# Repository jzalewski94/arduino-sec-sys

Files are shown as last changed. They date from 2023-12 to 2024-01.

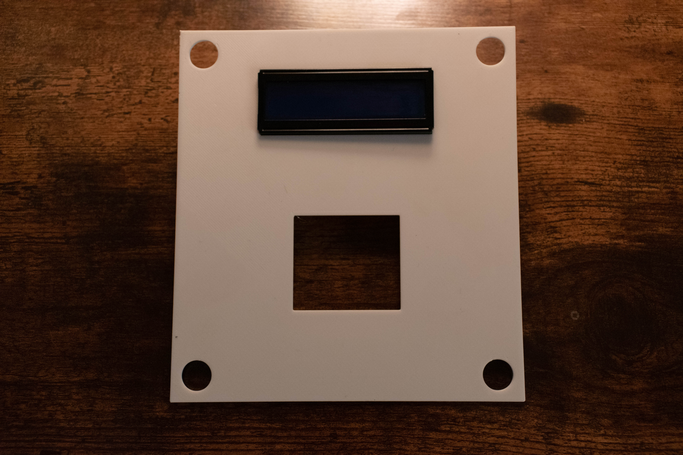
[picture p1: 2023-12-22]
models+3d-files/photos/20231221-DSC_1753.jpg

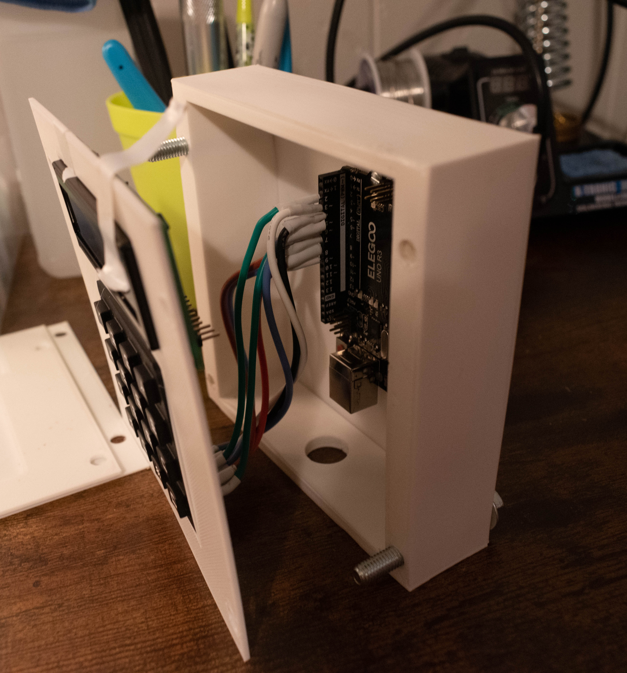
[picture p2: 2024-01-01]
models+3d-files/photos/20240102-DSC_1849.jpg

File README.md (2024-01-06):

Making a security system using an Arduino board. This will be a very basic system but may become more complicated in the future. I'm recording my steps here for anyone who wants to follow along to make a system like this. 

It will have horns, a magnetic sensor, and a control panel for the user to arm/disarm and set a password for the system. I plan on adding battery backup in the future to help protect against damage or power failure. I will also list the items used here and my electrical diagrams and schematics, along with any models and 3d print files I may generate or create. This will be modeled by myself to the best of my abilities. 

Items Used:

(2) 12V, 15W Horns (Bought)

(1) Magnetic Door Sensor (Bought)

(1) 3D Printed Control Box (Printed)

Amazon Link: https://www.amazon.com/hz/wishlist/ls/1QPFONZCPDYVN?ref_=wl_share

Mockup Update 1/6/2024:

The latest model files and mock-up files are the finalized mock-up models. I will now work on an Alpha design that will look more visually pleasing while remaining durable. 
The code for the controller is still being developed and worked on as well.

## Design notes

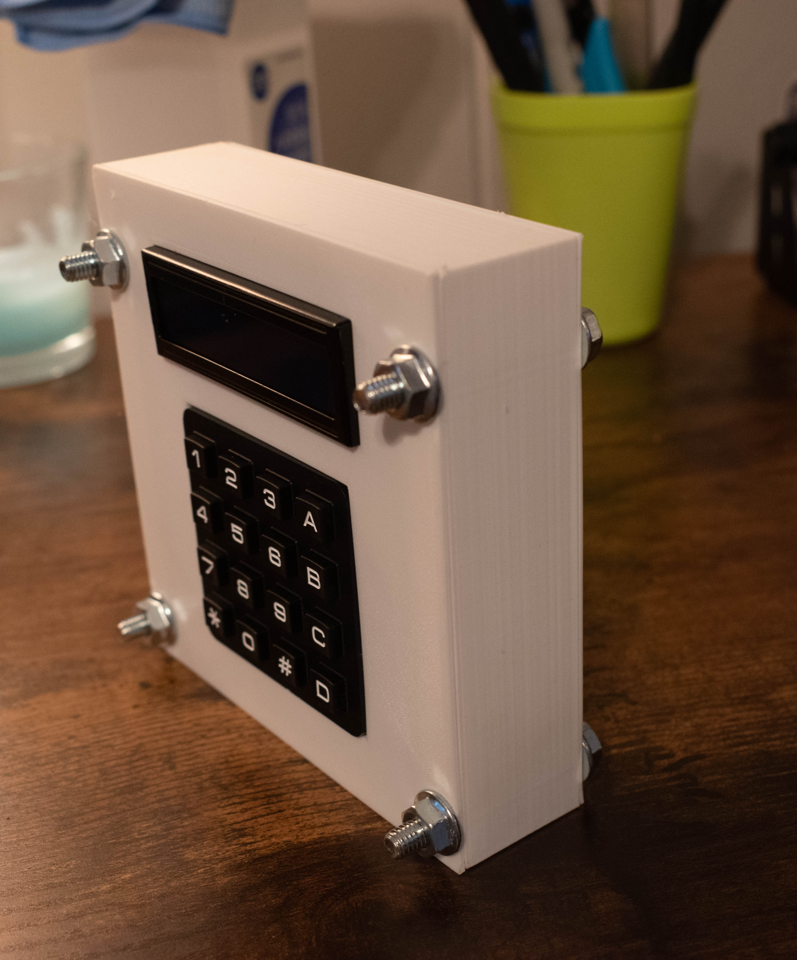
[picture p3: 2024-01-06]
models+3d-files/photos/20240107-DSC_1851.jpg

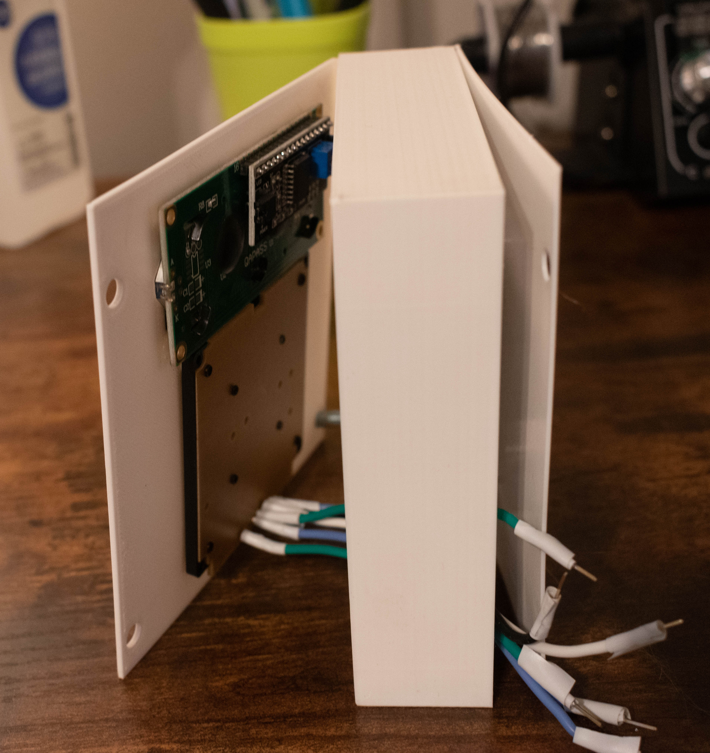
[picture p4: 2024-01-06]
models+3d-files/photos/20240107-DSC_1853.jpg

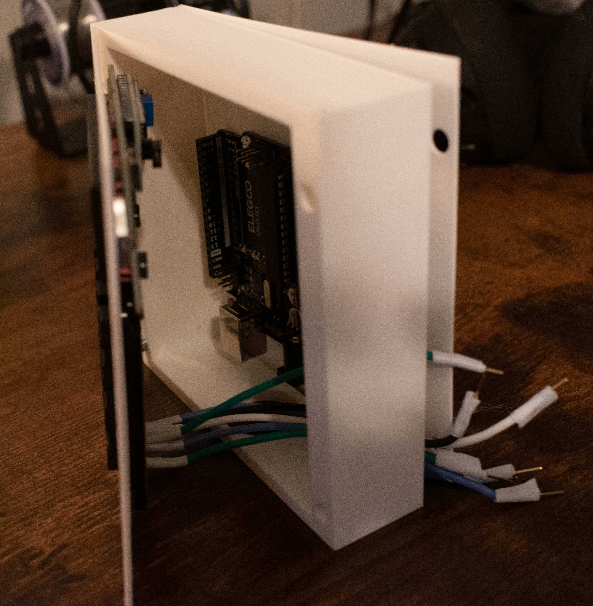
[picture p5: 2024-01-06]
models+3d-files/photos/20240107-DSC_1852.jpg

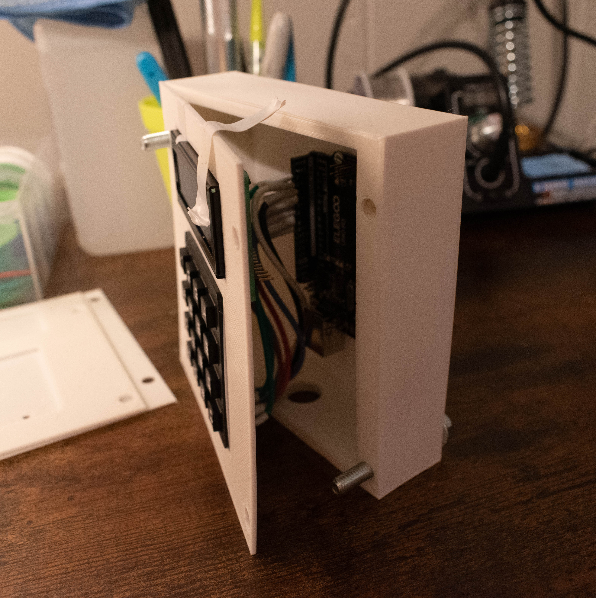
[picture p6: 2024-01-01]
models+3d-files/photos/20240102-DSC_1848.jpg

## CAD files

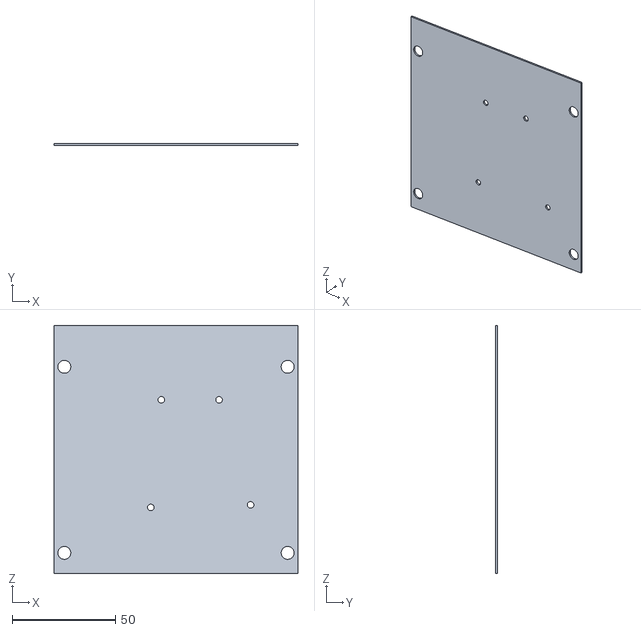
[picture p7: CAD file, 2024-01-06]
models+3d-files/back-plate-1.2.stl
118.0 x 1.00 x 120.0

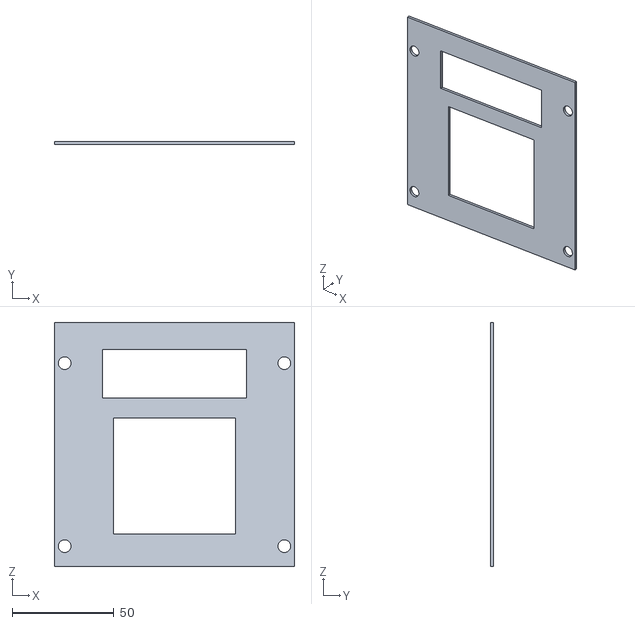
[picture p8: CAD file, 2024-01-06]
models+3d-files/front-plate-2.2.stl
118.0 x 1.50 x 120.0

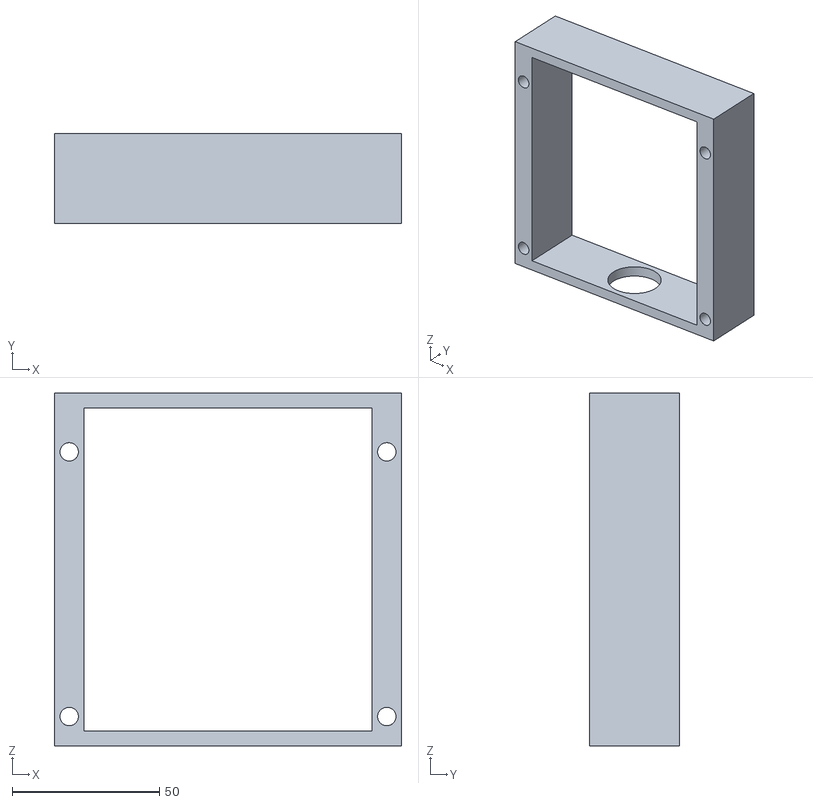
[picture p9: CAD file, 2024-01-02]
models+3d-files/housing-2.1.stl
118.0 x 30.5 x 120.0

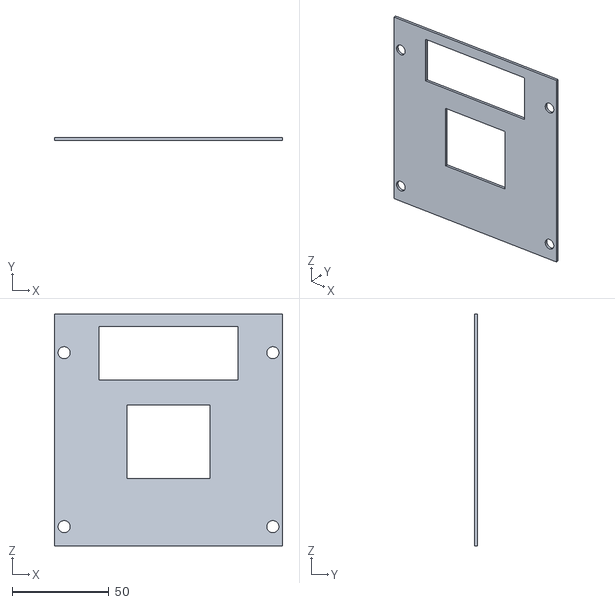
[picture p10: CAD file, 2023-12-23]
models+3d-files/front-plate-1.5.stl
118.0 x 1.50 x 120.0

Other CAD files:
models+3d-files/back-plate-1.1.stl
models+3d-files/front-plate-2.1.stl
models+3d-files/back-plate-1.0.stl
models+3d-files/front-plate-2.0.stl
models+3d-files/housing-2.0.stl
models+3d-files/front-plate-1.4.stl
models+3d-files/control-panel-mockup-1.4.f3d
models+3d-files/control-panel-mockup-2.0.f3d
models+3d-files/control-panel-mockup-2.2.f3d
models+3d-files/control-panel-mockup-2.3.f3d
models+3d-files/control-panel-mockup-2.4.f3d

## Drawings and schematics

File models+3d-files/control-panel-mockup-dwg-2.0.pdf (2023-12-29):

# 56.9 ⁶⁰

# 27.5 ⁷² Ø6.25

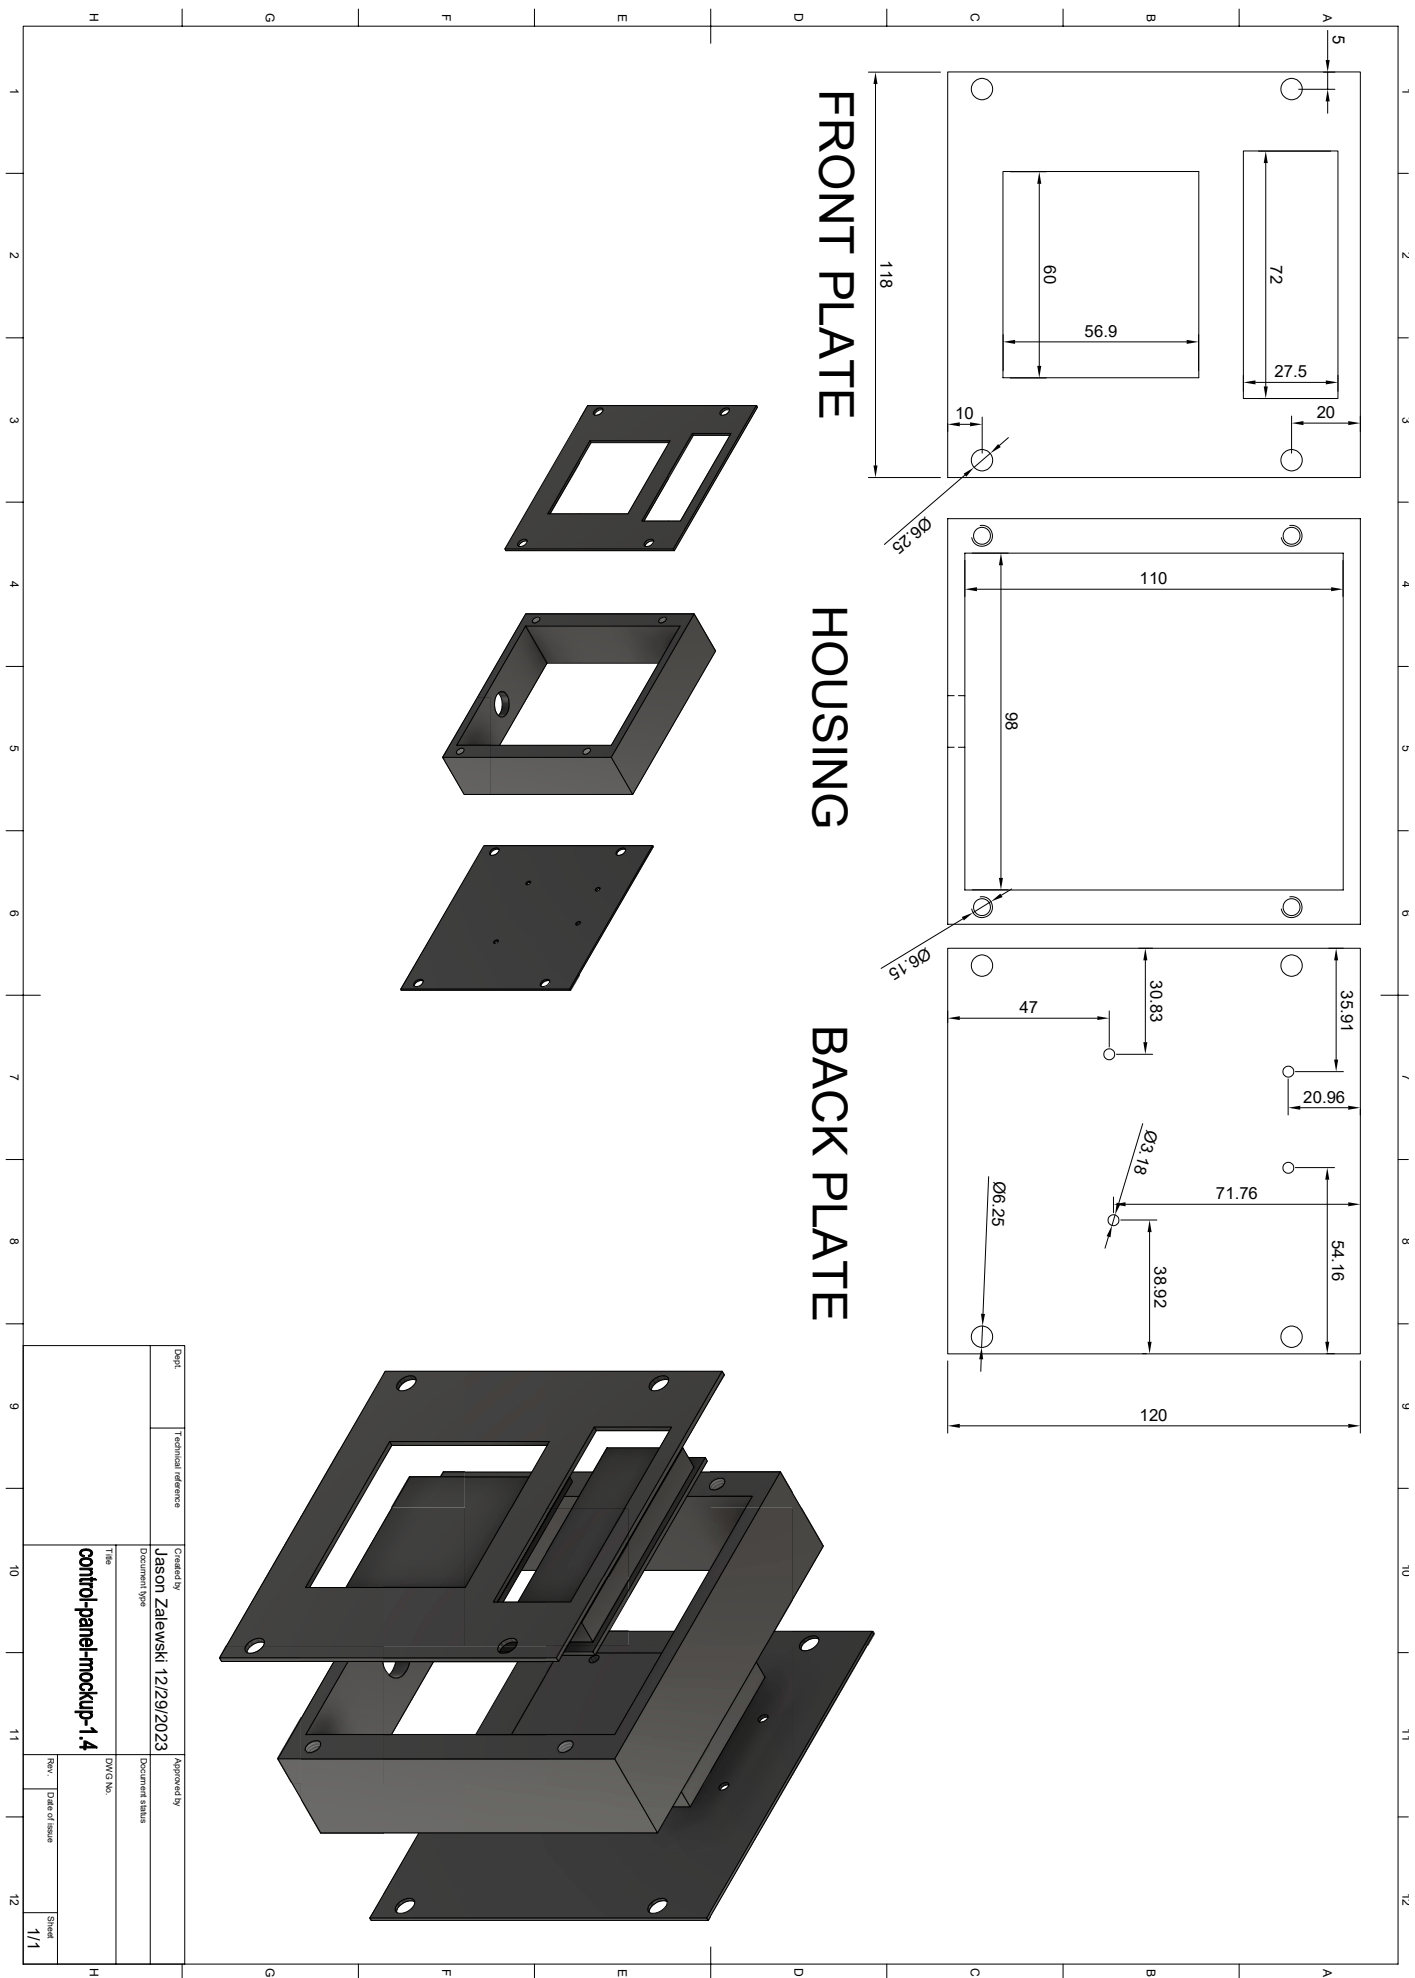
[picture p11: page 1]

2 1 3 4 5 6 7 8 9 10 11 12 2 1 3 4 5 6 7 8 9 10 11 12 HGFEDCBA HGFEDCBA Dept. Technical reference Created by Approved by Title DWG No. Document type Document status Rev. Date of issue Sheet 12/29/2023 1/1 Jason Zalewski 118
10 20 FRONT PLATE HOUSING BACK PLATE

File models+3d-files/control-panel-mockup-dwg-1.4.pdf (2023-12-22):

118 120

72

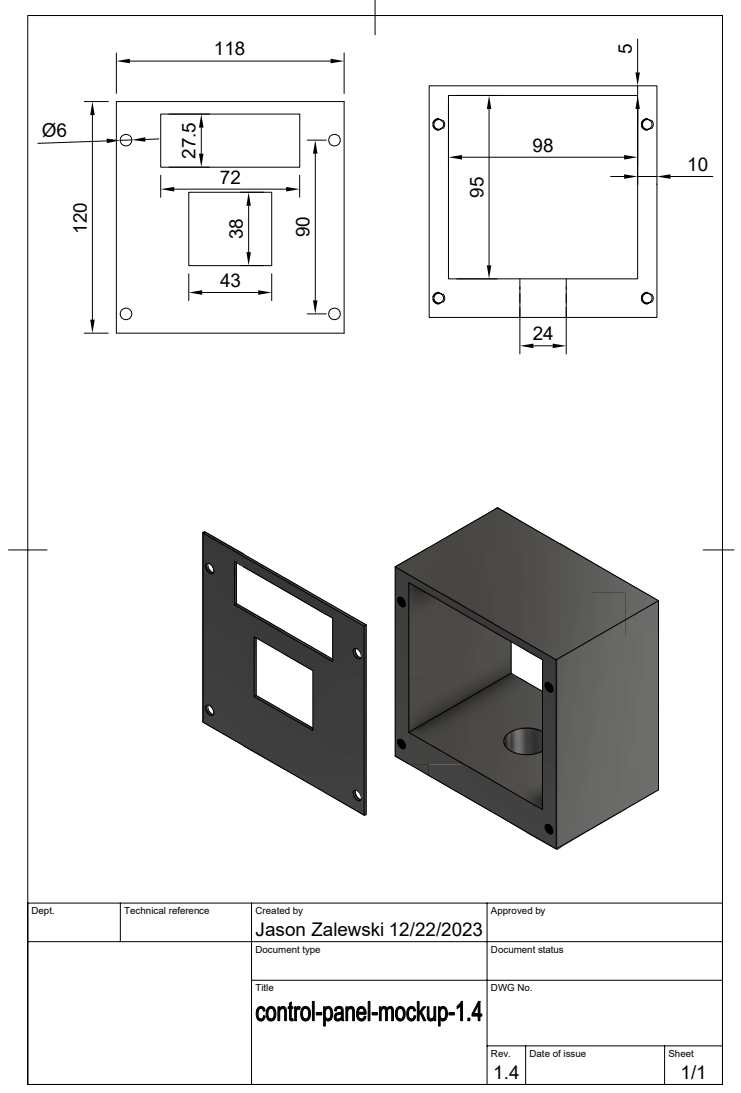
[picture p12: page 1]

Dept. | Technical reference | Created by Jason Zalewski 12/22/2023 | Approved by

Document type | Document status

Title | | | DWG No.

Rev. 1.4 | Date of issue | Sheet 1/1

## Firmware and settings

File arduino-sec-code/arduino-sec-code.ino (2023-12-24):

/*Here I am using the keypad libary to help me easily make a functional keypad.*/
#include <Keypad.h>




/*I have a bunch of consts here, things that aren't changing such as:
 * Armed/Disarmed LED lights on digital pin 10 and 11.
 * Door sensor on digital pin 13.
 * 
 * The row and column numbers because my physical keypad consists of a 4x4 Matrix.
 * 
 * Hard set usrpassword String. I am not currently using this, but will be worked on in the future.
 */
const int armedLED = 10;
const int disarmedLED = 11;
const int doorSensor = 13;
const int rowNum = 4;
const int colNum = 4;
const String usrPassword = "2194";







/*
 * Some booleans here, such as:
 * Is the alarm active/armed?
 * Did the password attempt succeed?
 * Has the alarm been triggered? (This one is being used the most)
 */
bool alarmActive = true;
bool passwordAttemptSucceed = false;

bool alarmTriggered = false;


/*
 * Int to hold the on/off value of my door sensor.
 */
int doorSensorVal = 0;



/*
 * I grabbed this code from the internet, so it was not written by me. 
 * You're making an array called keys that consists of 2 different axis (Row...Col...)
 * This is the physical layout of the keypad.
 */
char keys [rowNum][colNum] = {
  {'1','2','3', 'A'},
  {'4','5','6', 'B'},
  {'7','8','9', 'C'},
  {'*','0','#', 'D'}
};

/*
 * Here we are making variables of the byte type that will let us know where to place our wires into what pins. 
 * My keypad did not come with any documentation so this was trial and error for me.
 */
byte pin_rows[rowNum] = {9, 8, 7, 6}; //connect to the row pinouts of the keypad
byte pin_column[colNum] = {5, 4, 3, 2}; //connect to the column pinouts of the keypad


/*
 * I do not know how this function works, but this is essentially creating our keypad using the data above. 
 */
Keypad keypad = Keypad( makeKeymap(keys), pin_rows, pin_column, rowNum, colNum );

 
 
 /*
  * WIP Function. This and AlarmTriggered are WIP.
  */
 void PasswordAuth(){
    bool passwordCorr = false;
    int keyPresses = 0;
    char usrAttempt[3];

 
 
    while (passwordCorr == false && alarmTriggered == true){
      char keyPressed = keypad.getKey();

      switch(keypad.getState()){        
        case PRESSED:
        if( keyPressed == '2'){
          usrAttempt[0] = keyPressed;
          Serial.println(usrAttempt);
        }else if ( keyPressed == '1'){
          usrAttempt[1] = keyPressed;
          Serial.println(usrAttempt);
        }else if( keyPressed == '9'){
          usrAttempt[2] = keyPressed;
          Serial.println(usrAttempt);
        }else if( keyPressed == '4'){
          usrAttempt[3] = keyPressed;
          Serial.println(usrAttempt);

    }
  }
      if(usrAttempt[0] == '2' && usrAttempt[1] == '1' && usrAttempt[2] == '9' && usrAttempt[3] == '4'){
        
        Serial.println(usrAttempt);
        for(int i = 0; i < 4; i++){
          usrAttempt[i] = 0;
        }
        Serial.println(usrAttempt);
        passwordCorr = true;
         alarmTriggered = false;
        Serial.println(alarmTriggered);
        Serial.println(passwordCorr);
      }
      
}


 return;
}




/*
 * In my setup function, I open the serial monitor so I can use it for debugging.
 * I'm setting my LEDs to be an OUTPUT and the door sensor to be an INPUT.
 */
void setup() {
 Serial.begin(9600);

 pinMode(armedLED, OUTPUT);
 pinMode(disarmedLED, OUTPUT);
 pinMode(doorSensor, INPUT);

}



/*
 * In my loop function, I'm setting the doorSensorVal to read what ever is on digital pin 13(doorSensor).
 * 
 */
void loop() {
  doorSensorVal = digitalRead(doorSensor);
  
  /*
   * This is my first if statement in the program. It's checking to see if the door sensor value has changed.
   * If it switches to an ON state (1), it will set the alarm triggered value to TRUE and call the AlarmTriggered method.
   */
   if(doorSensorVal < 1){
    alarmTriggered = false;
  } else if(doorSensorVal == 1){
    alarmTriggered = true;
    AlarmTriggered();
    
  }



   /*
    * This IF statement is essentially here to control LEDs and give the user feedback. 
    * The first IF statement is checking to see if the alarm is active, not triggered, and the sensors aren't going off.
    * If all of this is met, it will set the armed LED to ON( HIGH) and print an message stating the alarmed is armed.
    *
    *The second IF statement is checking to see if the alarm is not active, has been reset and if the door sensor value isn't
    *being triggered (0). If all of these are met, it will ask if you want to re-arm the alarm. This IF statement should only be
    *called once the AlarmTriggered method has been satisified. 
    */
  if(alarmActive == true && alarmTriggered == false && doorSensorVal < 1){
    digitalWrite(armedLED, HIGH);
    Serial.println("Alarmed Armed.");
  } else if(alarmActive == false && alarmTriggered == false && doorSensorVal < 1){
    Serial.println("Do you wish to re arm the alarm?");
  }


  

}



/*
 * The AlarmTriggered method should only be called if the doorSensorVal goes off (ON, 1). The user will have to make sure
 * the door is securely closed or off the sensor before trying to reset the alarm. 
 */
void AlarmTriggered(){
    
      
      /*
       * When this method is called, it sets the alarm to be inactive. In the future, I will have to make the re-arming function. 
       * 
       * It is also setting the LEDs to their correct setting. (Red = HIGH for alarm on/inactive. Green = LOW)
       * An 'Alarm Triggered!" message also goes off.
       */
      alarmActive = false;
      digitalWrite(armedLED, LOW);
      digitalWrite(disarmedLED, HIGH);
      Serial.println("Alarmed Triggered!");

      
    /*
     * Here is a while loop that continues to run while the alarm variable is true. This is an WIP.
     */
     while(alarmTriggered == true){
        char passwordAttempt[4];
        int keyPressed = 4;
        int i = 0;
        int passwordCountdown = 10;
        Serial.println("Please enter the disarm password.");
        Serial.println("You have 10 seconds to enter the password, followed by #.");
        Serial.println(doorSensorVal);
        PasswordAuth();
       

          }

        }
        




 
  

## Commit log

2023-12-20 Added mock up for my control panel for the security system. This was made in Fusion360.
    Added the 3d file for the cover for my control panel.
    [control-box-frontcover.stl, control-box-mockup.f3d]
2023-12-20 Printed copy 1.0 of the face plate. Thru holes were way too big for the printer to accurately make. Adjusted the overall dimensions of the control panel housing and the front cover.
    Housing L x W: 150mm x 138mm
    Front Panel Cover L x W: 150mm x 138mm
    Front Panel Thru-Holes: 12mm Diameter
    Housing Tapped Holes: 10.27mm Diameter x 40mm Long (M12x1.75 Screw, RH Threads)
    Redid the overall mockup of the Control Planel. Added a mockup Elegoo PCB that will sit inside the panel on the side. Adjust mock up LED and Keypad
    to fit inside the panel and have no conflicting issues.
    [control-box-mockup-1.1.f3d, front-plate-1.1.stl]
2023-12-20 Added a Models and 3D files folder as to not clog up the main folder.
    Adjusted the length of the LCD component as I did not measure correctly. Changes were
    made on the front cover piece and the LCD mock up.
    LCD length: 70mm --->> 72mm (Adjusted)
    [control-box-mockup-1.1.f3d, control-box-mockup-1.2.f3d, front-plate-1.1.stl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]
2023-12-20 control-panel-mockup-1.3 & housing-1.0
    -Added a thru hole to the housing part of the mock up. This allows space for wires to go through.
    The diameter of this hole may change depending on what type of hardware I can find.
    -Added the .stl file for the housing. This will be version 1.0.
    [control-panel-mockup-1.3.f3d]
2023-12-20 Added drawings for the control panel mock up.
    -Added a pdf of the prints for the mock up control panel.
2023-12-20 Edited control panel mockup drawing.
    -Added a side view profile of both the housing and front cover plate.
2023-12-21 Removed outdated files
    -Removed outdate files.
    [control-box-frontcover.stl, control-box-mockup-1.1.f3d, control-box-mockup.f3d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]
2023-12-22 Add archives folder, add 1.4 mockup, and more
    -Added an archives folder and moved all previous versions to it.
    -Added mock up version 1.4. Listed changes to each component will be below.
    [Housing 1.1 & Front Cover 1.4]
    -Reduced over height and width of housing and front cover.
    Previous L x W: 150m L x 138mm W >>> NEW 120mm L x 118mm W
    -Reduced thru hole and tapped thread size. After printing the 1.0 version, I did
    not like how big the threads were.
    Previous tapped thread size: M12x1.75 >>> NEW M6x1.0
    Previous thru hole sie: 12mm >>> NEW 6mm
    -Reduced the clearance between the LCD cutout and keypad cut so they are closer together,
    saving more room.
    Previous LCD x Keypad c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
    [control-box-mockup-1.1.f3d, control-box-mockup-1.2.f3d, control-panel-mockup-1.3.f3d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]
2023-12-22 Add photos of printed models and other things.
    -Added a photo of the printed 1.3 front panel model.
    -Added a photo of the door magnetic sensors and the 2 horns. This is how
    I have my inital circuit set up. Will add an annonated photo of circuit.
2023-12-23 Modified front plate thru hole
    -Changed thru hole on the front plate
    OLD 6mm >>> NEW 6.5mm
    [front-plate-1.4.stl, front-plate-1.5.stl]
2023-12-24 Added arduino code
    -Added a folder for my arduino code.
    -Arduino code consists of a basic I/O loop that looks for
    the magnetic door sensor to be open and will send a signal
    to the horns to go off.
    [WIP]
    -Currently working on a function that will allow for a password system to arm/disarm/ and reset the alarm.
    [TODO]
    -Will comment all working code for readability.
    [arduino-sec-code.ino]
2023-12-24 Modified sec-sys code
    -Spent time going through useable code to document how it works.
    -Continued work on a password/arming system. The basic logic is there, you enter in a hardcode password,
    in this case '2194' and whenever you press a key, it logs it to an array. I have some logic checking to see
    if this array matches '2194' and if it does, it will ask if you want to re arm.
    [Password / Arming System WIP]
    -Need to make some logic that checks if you enter a wrong key and resets the password process.
    [arduino-sec-code.ino]
2023-12-29 20.0 Version of the Control Planel mock up
    -Added a new back plate and decreased the thickness of the box.
    I'm able to do this because I've decided to place the PCB on the back
    plate.
    Old Thickness: 75 mm >>> 30.5 mm
    New back plate part added as apart of the assembly.
    -Adjusted PCB and Keyboard knockout dimensions.
    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
    [back-plate-1.0.stl, control-panel-mockup-1.4.f3d, control-panel-mockup-2.0.f3d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]
2023-12-29 2.0 Version of the Control Planel mock up
    I've received the keypad in the mail so I was able to take actual
    physical measurements.
    -Added adjusted drawings and moved outdated files to archives.
    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
    [back-plate-1.0.stl, control-panel-mockup-1.4.f3d, control-panel-mockup-2.0.f3d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]
2023-12-29 Added notes for calling out pinouts.
    -Called out pin locations for board and keypad.
2024-01-01 Minor changes to front and back plates
    -After printing out the front plate, the LCD component did not snap into
    it's cutout the way I liked. So I made it slightly smaller to adjust.
    -Also moved the LCD cutout down some to make room for the wires and pins from the main board.
    -Moved the PCB thru holes on the back over 15mm to the side to also make more room inside the box.
    [back-plate-1.0.stl, back-plate-1.1.stl, control-panel-mockup-2.0.f3d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]
2024-01-01 Edited pinouts, added photos of 2.0 mock up.
    -Edited the pinouts for the Keypad to PCB, wires were soldered
    to the Keypad so these are permanent.
    -Added photos of the 2.0 Housing, 2.1 Front plate, and 1.1 back plate.
    I am satisifed with the overall dimensions of the control panel. I still
    need to adjust the dimensions of the LCD cutout because I want it to snap
    in more securely.
    As you can see, the keypad dimensions were way different when I actually got the
    physicaly keypad compared to the dimensions Amazon gave.
    I will also change the threaded holes into thru holes because the threads serve no purpose.
    There will also need to be LED knockouts on the front plate as well.
2024-01-02 Modified housing, archived old things.
    -Added the thru holes instead of the threaded holes for the housing.
    -Made the hole for the cabling to be bigger after seeing the old hole.
    OLD 15mm Thru Hole >>> NEW 25 mm Thru Hole
    [control-panel-mockup-2.2.f3d, control-panel-mockup-2.3.f3d, housing-2.0.stl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]
2024-01-06 Adjusted front and back plate
    -Adjusted the LCD cutout dimensions after receiving the physical component
    I will be using.
    OLD LENGTH 72MM >>> NEW 71MM
    OLD WIDTH 27.5 >> NEW 24MM
    -Moved the thru holes for the Elegoo controller on the back plate. After soldering
    the wires and making things more pernament.
    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
    [back-plate-1.1.stl, back-plate-1.2.stl, control-panel-mockup-2.3.f3d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]
2024-01-06 Finalized mock up photos
    -Added photos of the finalized design of my mock
    -up control panel box. I am satisfied with the design,
    next I will work on making it look more visually pleasing.
    TO DO:
    -Make a more discreet fastner design, but it still has to be durable.
    Will most likely remove the bolts and go with a snap design.
    -Pleased with the keypad and LCD cutouts, they snap in nicely. I will
    glue the perimieter of these components to keep them in the knock out.
    -Will have to figure out how I want to mount the control panel while
    keeping it visually pleasing and durable.
    -Removed old archives folders as those designs are not needed anymore.
    This is the finalized Mock up design, next I w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
    [back-plate-1.0.stl, back-plate-1.1.stl, control-box-mockup-1.1.f3d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]
